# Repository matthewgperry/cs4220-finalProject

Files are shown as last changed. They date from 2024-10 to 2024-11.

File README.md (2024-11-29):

# Real-Time Embedded Systems (CS 4220/6235) Final Project - Fall 2024

## Overview

This repository contains the hardware schematics (PCB design files) in `occupancySensorBoard`, the initial Arduino scripts in `arduino`, and the ESP32 firmware in `firmware`.

The firmware defines an occupancy sensor with the DFRobot C4001 MM-Wave sensor with the Matter standard.

## Setup

Note: The ESP-IDF has an unresolved bug, requiring a manual workaround. The bug I experienced is described [here](https://esp32.com/viewtopic.php?t=42744).

1. Choose an install method for the ESP-IDF. I used the Linux install method. Follow the instructions [here](https://docs.espressif.com/projects/esp-idf/en/v5.3.1/esp32/get-started/index.html).

2. Install [ESP-Matter](https://docs.espressif.com/projects/esp-matter/en/latest/esp32/developing.html).

3. Clone this repository.

4. Source the ESP-IDF and ESP-Matter environment variables.

5. Navigate to the `firmware` directory.

6. Run `idf.py set-target esp32c6` to set the target board to the ESP32-C6.

7. Run `idf.py menuconfig` to configure the firmware (WiFi setup, flash size, etc).

8. Run `idf.py build` to build the firmware.

## PCB Production

The PCB design files are in the `occupancySensorBoard` directory. The PCB was designed in KiCad.

The PCB was produced by JLCPCB. The Gerber, BOM, and CPL files are in the `occupancySensorBoard/jlcpcb` directory.

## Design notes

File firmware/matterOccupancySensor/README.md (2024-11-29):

# Matter Occupany Sensor Firmware

## Description

This firmware, built with ESP-IDF v5.2.1, initalizes control of a DFRobot C4001 MM-Wave sensor and sends data to a variety of smart home hubs with the Matter framework.

## Setup

#### Clean Build

ESP-IDF seems to have issues fully removing the build directory, so do it manually.

#### Setting Target

In the demo case, an ESP32-C6 is used.
So `idf.py set-target esp32c6` should be ran.

#### Configuration

`idf.py menuconfig`

#### Building and Flash

`idf.py build flash monitor`

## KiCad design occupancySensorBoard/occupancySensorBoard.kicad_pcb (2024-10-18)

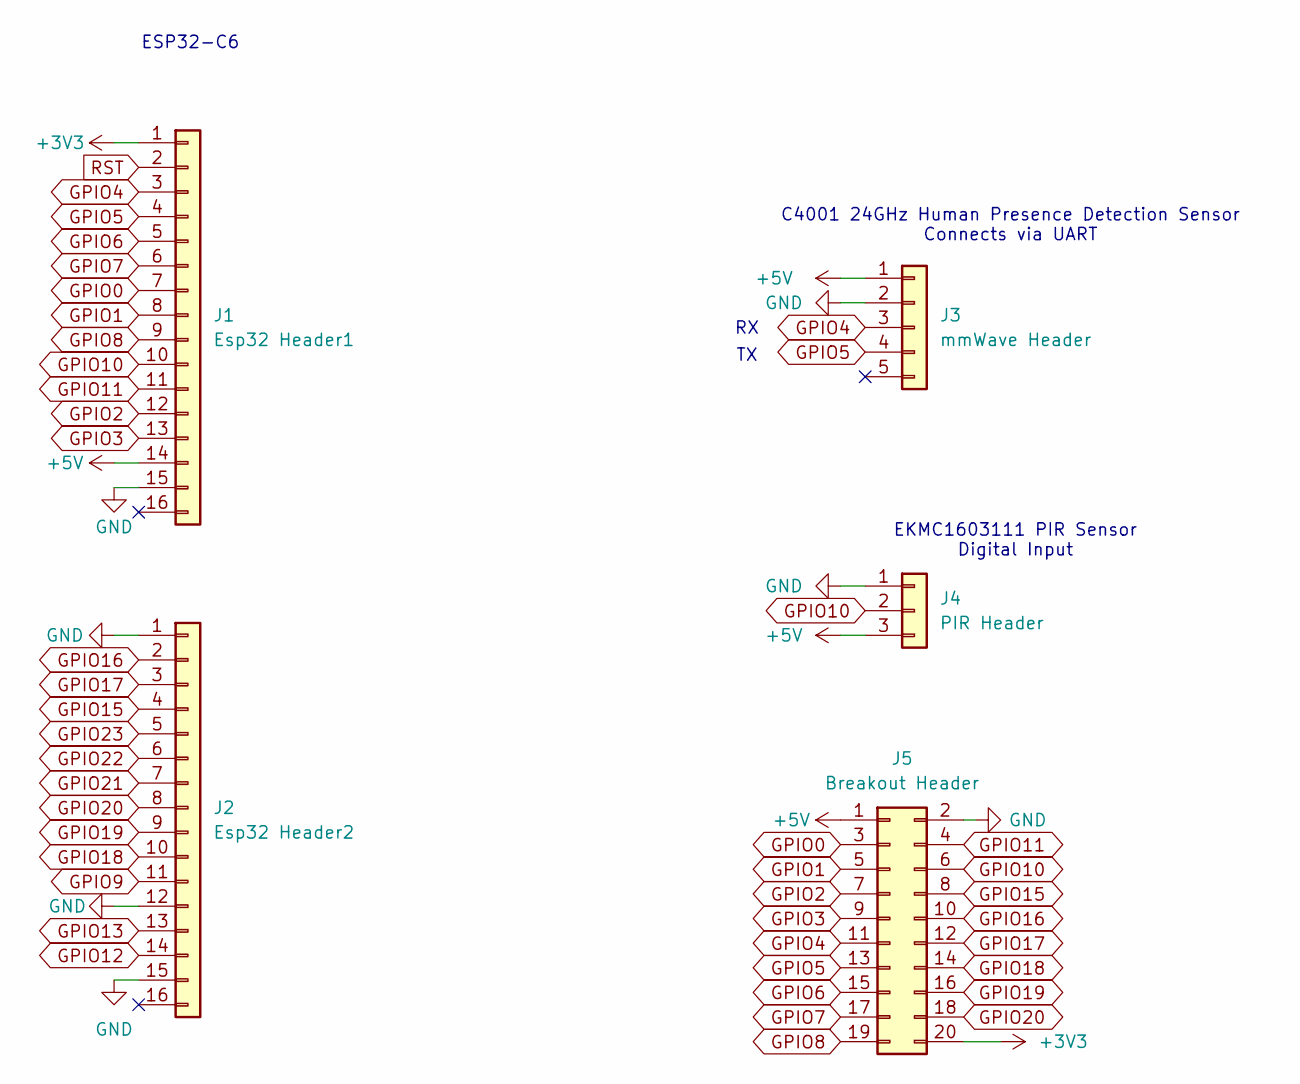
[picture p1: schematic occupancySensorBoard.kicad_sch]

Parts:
J1: Esp32 Header1; PinHeader_1x16_P2.54mm_Vertical
J2: Esp32 Header2; PinHeader_1x16_P2.54mm_Vertical
J3: mmWave Header; PinHeader_1x05_P2.54mm_Vertical
J4: PIR Header; 917-47-103-41005000
J5: Breakout Header; PinHeader_2x10_P2.54mm_Vertical

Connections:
+3V3: J1.1, J5.20
+5V: J1.14, J3.1, J4.3, J5.1
GND: J1.15, J2.1, J2.12, J2.15, J3.2, J4.1, J5.2
GPIO0: J1.7, J5.3
GPIO1: J1.8, J5.5
GPIO2: J1.12, J5.7
GPIO3: J1.13, J5.9
GPIO4: J1.3, J3.3, J5.11
GPIO5: J1.4, J3.4, J5.13
GPIO6: J1.5, J5.15
GPIO7: J1.6, J5.17
GPIO8: J1.9, J5.19
GPIO9: J2.11
GPIO10: J1.10, J4.2, J5.6
GPIO11: J1.11, J5.4
GPIO12: J2.14
GPIO13: J2.13
GPIO15: J2.4, J5.8
GPIO16: J2.2, J5.10
GPIO17: J2.3, J5.12
GPIO18: J2.10, J5.14
GPIO19: J2.9, J5.16
GPIO20: J2.8, J5.18
GPIO21: J2.7
GPIO22: J2.6
GPIO23: J2.5
RST: J1.2

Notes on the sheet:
C4001 24GHz Human Presence Detection Sensor Connects via UART
EKMC1603111 PIR Sensor Digital Input
ESP32-C6

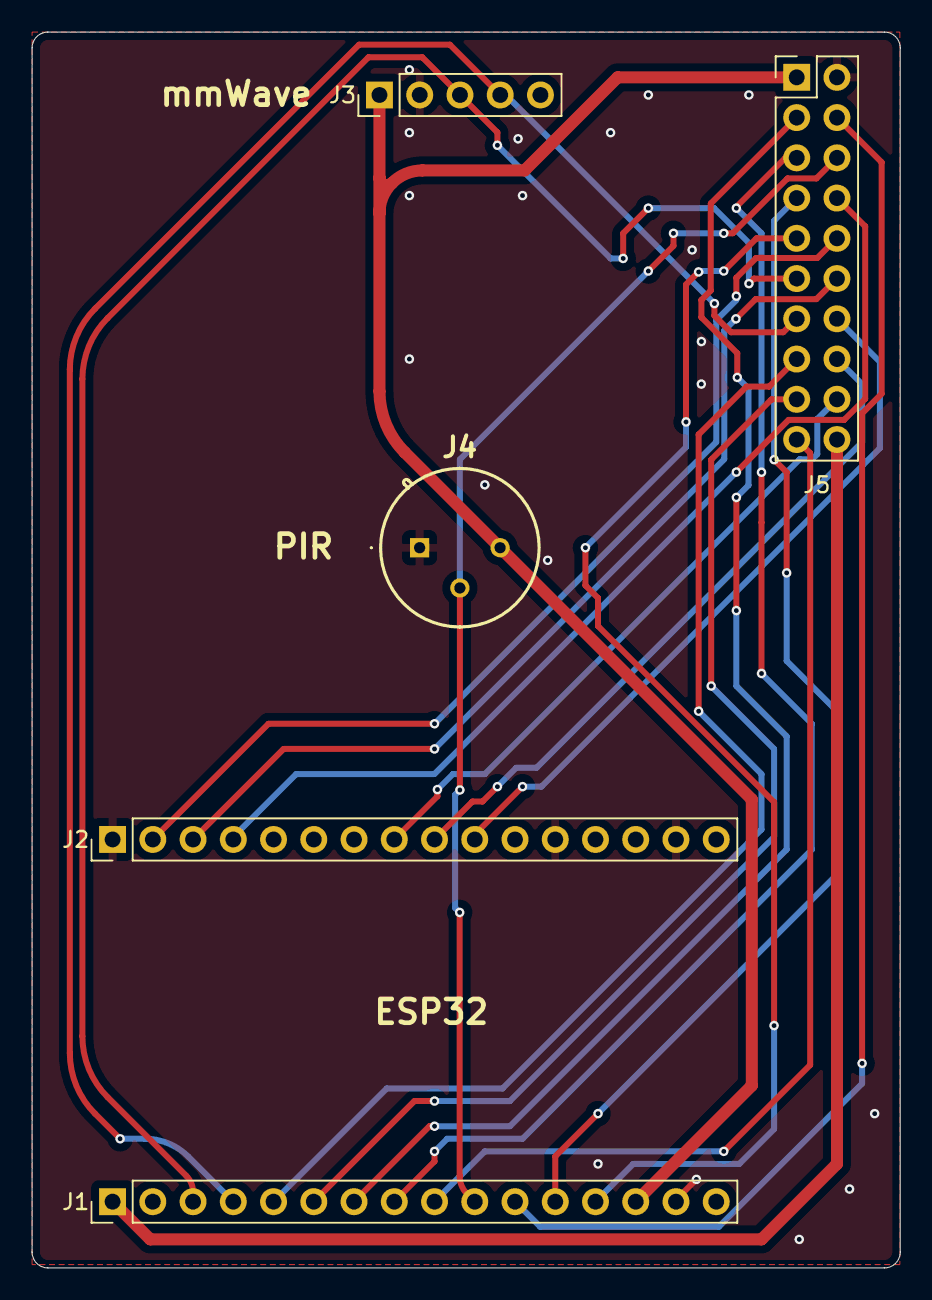
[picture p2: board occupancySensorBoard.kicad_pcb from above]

Board: 2 copper layers, 54.8 x 78.0 mm, 5 parts (0 on the bottom side), 20 nets.

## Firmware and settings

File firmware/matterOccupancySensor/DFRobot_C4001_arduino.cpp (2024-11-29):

/*!
 * @file DFRobot_C4001.cpp
 * @brief Define the basic structure of the DFRobot_C4001 class, the implementation of the basic methods
 * @copyright	Copyright (c) 2010 DFRobot Co.Ltd (http://www.dfrobot.com)
 * @license The MIT License (MIT)
 * @author [ZhixinLiu](zhixin.liu@dfrobot.com)
 * @version V1.0
 * @date 2024-02-02
 * @url https://github.com/DFRobot/DFRobot_C4001
 */
#include "DFRobot_C4001_arduino.h"

DFRobot_C4001::DFRobot_C4001(){}
DFRobot_C4001::~DFRobot_C4001(){}

sSensorStatus_t DFRobot_C4001::getStatus(void)
{
  sSensorStatus_t data;
  uint8_t temp[100] = {0};
  uint8_t len = 0;
  if(uartI2CFlag == I2C_FLAG){
    uint8_t temp = 0;
    readReg(REG_STATUS, &temp, (uint8_t)1);
    data.workStatus = (temp&0x01);
    data.workMode   = (temp&0x02) >> 1;
    data.initStatus = (temp&0x80) >> 7;
  }else{  
    sAllData_t allData;
    readReg(0, temp, 100);
    writeReg(0, (uint8_t *)START_SENSOR, strlen(START_SENSOR));
    while(len == 0){
      delay(1000);
      len = readReg(0, temp, 100);
      allData = anaysisData(temp ,len);
    }
    data.workStatus = allData.sta.workStatus;
    data.workMode   = allData.sta.workMode;
    data.initStatus = allData.sta.initStatus;
  }
  return data;
}

bool DFRobot_C4001::motionDetection(void)
{
  if(uartI2CFlag == I2C_FLAG){
    uint8_t temp = 0;
    readReg(REG_RESULT_STATUS, &temp, (uint8_t)1);
    if(temp&0x01){
      return true;
    }
    return false;
  }else{
    static bool old = false;
    uint8_t status = 0;
    uint8_t len = 0;
    uint8_t temp[100] = {0};
    sAllData_t data;
    len = readReg(0, temp, 100);
    data = anaysisData(temp ,len);
    if(data.exist){
      old = (bool)status;
      return (bool)data.exist;
    }else{
      return (bool)old;
    }
  }
}

void DFRobot_C4001::setSensor(eSetMode_t mode)
{
  uint8_t temp = mode;
  if(uartI2CFlag == I2C_FLAG){
    if(mode == eStartSen){
      writeReg(REG_CTRL0, &temp, (uint8_t)1);
      delay(200);  // must timer
    }else if(mode == eStopSen){
      writeReg(REG_CTRL0, &temp, (uint8_t)1);
      delay(200);  // must timer
    }else if(mode == eResetSen){
      writeReg(REG_CTRL0, &temp, (uint8_t)1);
      delay(1500);  // must timer
    }else if(mode == eSaveParams){
      writeReg(REG_CTRL1, &temp, (uint8_t)1);
      delay(500);  // must timer
    }else if(mode == eRecoverSen){
      writeReg(REG_CTRL1, &temp, (uint8_t)1);
      delay(800);  // must timer
    }else if(mode == eChangeMode){
      writeReg(REG_CTRL1, &temp, (uint8_t)1);
      delay(1500);  // must timer
    }
  }else{
    if(mode == eStartSen){
      writeReg(0, (uint8_t *)START_SENSOR, strlen(START_SENSOR));
      delay(200);  // must timer
    }else if(mode == eStopSen){
      writeReg(0, (uint8_t *)STOP_SENSOR, strlen(STOP_SENSOR));
      delay(200);  // must timer
    }else if(mode == eResetSen){
      writeReg(0, (uint8_t *)RESET_SENSOR, strlen(RESET_SENSOR));
      delay(1500);  // must timer
    }else if(mode == eSaveParams){
      writeReg(0, (uint8_t *)STOP_SENSOR, strlen(STOP_SENSOR));
      delay(200);  // must timer
      writeReg(0, (uint8_t *)SAVE_CONFIG, strlen(SAVE_CONFIG));
      delay(800);  // must timer
      writeReg(0, (uint8_t *)START_SENSOR, strlen(START_SENSOR));
    }else if(mode == eRecoverSen){
      writeReg(0, (uint8_t *)STOP_SENSOR, strlen(STOP_SENSOR));
      delay(200);
      writeReg(0, (uint8_t *)RECOVER_SENSOR, strlen(RECOVER_SENSOR));
      delay(800);  // must timer
      writeReg(0, (uint8_t *)START_SENSOR, strlen(START_SENSOR));
      delay(500);
    }
  }
}

bool DFRobot_C4001::setSensorMode(eMode_t mode)
{
  if(uartI2CFlag == I2C_FLAG){
    sSensorStatus_t data;
    data = getStatus();
    if(data.workMode == mode){
      return true;
    }else{
      setSensor(eChangeMode);
      data = getStatus();
      if(data.workMode == mode){
        return true;
      }else{
        return false;
      }
    }
  }else{
    sensorStop();
    if(mode == eExitMode){
      writeReg(0, (uint8_t *)EXIST_MODE, strlen(EXIST_MODE));
      delay(50);  
    }else{
      writeReg(0, (uint8_t *)SPEED_MODE, strlen(SPEED_MODE));
      delay(50);
    }
    delay(50);
    writeReg(0, (uint8_t *)SAVE_CONFIG, strlen(SAVE_CONFIG));
    delay(500);
    writeReg(0, (uint8_t *)START_SENSOR, strlen(START_SENSOR));
    delay(100);
    return true;
  }
}

bool DFRobot_C4001::setTrigSensitivity(uint8_t sensitivity)
{
  uint8_t temp = sensitivity;
  if(sensitivity > 9){
    return false;
  }
  if(uartI2CFlag == I2C_FLAG){
    writeReg(REG_TRIG_SENSITIVITY, &temp, (uint8_t)1);
    setSensor(eSaveParams);
    return true;
  }else{
    String data = "setSensitivity 255 1";
    data[19] = sensitivity + 0x30;
    writeCMD(data, data, (uint8_t)1);
    return true;
  }
}

uint8_t DFRobot_C4001::getTrigSensitivity(void)
{
  if(uartI2CFlag == I2C_FLAG){
    uint8_t temp = 0;
    readReg(REG_TRIG_SENSITIVITY, &temp, (uint8_t)1);
    return temp;
  }else{
    sResponseData_t responseData;
    uint8_t temp[100] = {0};
    readReg(0, temp, 100);
    String data = "getSensitivity";
    responseData = wRCMD(data, (uint8_t)1);
    if(responseData.status){ 
      return responseData.response1;
    }
    return 0;
  }
}

bool DFRobot_C4001::setKeepSensitivity(uint8_t sensitivity)
{
  uint8_t temp = sensitivity;
  if(sensitivity > 9){
    return false;
  }
  if(uartI2CFlag == I2C_FLAG){
    writeReg(REG_KEEP_SENSITIVITY, &temp, (uint8_t)1);
    setSensor(eSaveParams);
    return true;
  }else{
    String data = "setSensitivity 1 255";
    data[15] = sensitivity + 0x30;
    writeCMD(data, data, (uint8_t)1);
    return true;
  }
}

uint8_t DFRobot_C4001::getKeepSensitivity(void)
{
  if(uartI2CFlag == I2C_FLAG){
    uint8_t temp = 0;
    readReg(REG_KEEP_SENSITIVITY, &temp, (uint8_t)1);
    return temp;
  }else{
    sResponseData_t responseData;
    uint8_t temp[100] = {0};
    readReg(0, temp, 100);
    String data = "getSensitivity";
    responseData = wRCMD(data, (uint8_t)1);
    if(responseData.status){
      return responseData.response2;
    }
    return 0;
  }
}

bool DFRobot_C4001::setDelay(uint8_t trig , uint16_t keep)
{
  if(trig > 200){
    return false;
  }
  if(keep < 4 || keep > 3000){
    return false;
  }
  if(uartI2CFlag == I2C_FLAG){
    uint8_t temp[3] = {0};
    temp[0] = trig;
    temp[1] = keep;
    temp[2] = keep>>8;
    writeReg(REG_TRIG_DELAY, temp, (uint8_t)3);
    setSensor(eSaveParams);
    return true;
  }else{
    String data = "setLatency ";
    data += String((float)trig*0.01, 1);
    data += " ";
    data += String((float)keep*0.5, 1);
    writeCMD(data, data, (uint8_t)1);
    return true;
  }
}
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

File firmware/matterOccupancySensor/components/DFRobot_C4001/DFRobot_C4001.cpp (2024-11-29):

#include "DFRobot_C4001.h"
#include "driver/uart.h"
#include "esp_log.h"
#include "esp_timer.h"
#include <string>
#include <cstring>
#include <stddef.h>

#define UART_NUM UART_NUM_0
#define BUF_SIZE 1024
static const char *TAG = "DFRobot_C4001";

DFRobot_C4001::DFRobot_C4001() : _addr(DEVICE_ADDR_0) {
    memset(&_buffer, 0, sizeof(sPrivateData_t));
}

// Add the missing destructor definition
DFRobot_C4001::~DFRobot_C4001() {
}


DFRobot_C4001_UART::DFRobot_C4001_UART(int tx_pin, int rx_pin, uint32_t baud_rate)
    : DFRobot_C4001(), tx_pin(tx_pin), rx_pin(rx_pin), baud_rate(baud_rate) {}

bool DFRobot_C4001_UART::begin() {
    const uart_config_t uart_config = {
        .baud_rate = baud_rate,
        .data_bits = UART_DATA_8_BITS,
        .parity = UART_PARITY_DISABLE,
        .stop_bits = UART_STOP_BITS_1,
        .flow_ctrl = UART_HW_FLOWCTRL_DISABLE
    };
    uart_param_config(UART_NUM, &uart_config);
    uart_set_pin(UART_NUM, tx_pin, rx_pin, UART_PIN_NO_CHANGE, UART_PIN_NO_CHANGE);
    uart_driver_install(UART_NUM, BUF_SIZE * 2, 0, 0, NULL, 0);
    return true;
}


void DFRobot_C4001_UART::writeReg(uint8_t reg, uint8_t *data, uint8_t len) {
    uart_write_bytes(UART_NUM, (const char *)data, len);
}

int16_t DFRobot_C4001_UART::readReg(uint8_t reg, uint8_t *data, uint8_t len) {
    uint16_t i = 0;
    uint32_t start_time = esp_timer_get_time() / 1000;
    while ((esp_timer_get_time() / 1000) - start_time < TIME_OUT) {
        int length = 0;
        uart_get_buffered_data_len(UART_NUM, (size_t *)&length);
        if (length > 0) {
            int read_len = uart_read_bytes(UART_NUM, data + i, len - i, 20 / portTICK_RATE_MS);
            if (read_len > 0) {
                i += read_len;
                if (i >= len) return len;
            }
        }
    }
    return i;
}

void DFRobot_C4001::setSensor(eSetMode_t mode) {
    if (mode == eStartSen) {
        writeReg(0, (uint8_t *)START_SENSOR, strlen(START_SENSOR));
        vTaskDelay(pdMS_TO_TICKS(200));
    } else if (mode == eStopSen) {
        writeReg(0, (uint8_t *)STOP_SENSOR, strlen(STOP_SENSOR));
        vTaskDelay(pdMS_TO_TICKS(200));
    } else if (mode == eResetSen) {
        writeReg(0, (uint8_t *)RESET_SENSOR, strlen(RESET_SENSOR));
        vTaskDelay(pdMS_TO_TICKS(1500));
    } else if (mode == eSaveParams) {
        writeReg(0, (uint8_t *)STOP_SENSOR, strlen(STOP_SENSOR));
        vTaskDelay(pdMS_TO_TICKS(200));
        writeReg(0, (uint8_t *)SAVE_CONFIG, strlen(SAVE_CONFIG));
        vTaskDelay(pdMS_TO_TICKS(800));
        writeReg(0, (uint8_t *)START_SENSOR, strlen(START_SENSOR));
    } else if (mode == eRecoverSen) {
        writeReg(0, (uint8_t *)STOP_SENSOR, strlen(STOP_SENSOR));
        vTaskDelay(pdMS_TO_TICKS(200));
        writeReg(0, (uint8_t *)RECOVER_SENSOR, strlen(RECOVER_SENSOR));
        vTaskDelay(pdMS_TO_TICKS(800));
        writeReg(0, (uint8_t *)START_SENSOR, strlen(START_SENSOR));
        vTaskDelay(pdMS_TO_TICKS(500));
    }
}

bool DFRobot_C4001::motionDetection(void) {
    static bool old = false;
    uint8_t status = 0;
    uint8_t len = 0;
    uint8_t temp[100] = {0};
    sAllData_t data;
    len = readReg(0, temp, 100);
    data = anaysisData(temp, len);
    if (data.exist) {
        old = (bool)status;
        ESP_LOGI(TAG, "Occupancy: %d", (bool)status);
        return (bool)data.exist;
    } else {
        return (bool)old;
        ESP_LOGI(TAG, "Occupancy: %d", (bool)old);
    }
}

sAllData_t DFRobot_C4001::anaysisData(uint8_t* data, uint8_t len)
{
    sAllData_t allData;
    uint8_t location = 0;
    
    // Initialize the structure with zeros
    memset(&allData, 0, sizeof(sAllData_t));
    
    // Find the start of the data marked by '$'
    for(uint8_t i = 0; i < len; i++) {
        if(data[i] == '$') {
            location = i;
            break;
        }
    }
    
    // Return empty structure if no valid start found
    if(location == len) {
        return allData;
    }
    
    // Check for Human Presence Detection mode
    if(strncmp((const char *)(data + location), "$DFHPD", strlen("$DFHPD")) == 0) {
        allData.sta.workMode = eExitMode;
        allData.sta.workStatus = 1;
        allData.sta.initStatus = 1;
        
        if(data[location + 7] == '1') {
            allData.exist = 1;
        } else {
            allData.exist = 0;
        }
    }
    // Check for Speed Detection mode
    else if(strncmp((const char *)(data + location), "$DFDMD", strlen("$DFDMD")) == 0) {
        allData.sta.workMode = eSpeedMode;
        allData.sta.workStatus = 1;
        allData.sta.initStatus = 1;
        
        // Create a temporary buffer for string manipulation
        char temp_buffer[256];
        if (len - location >= sizeof(temp_buffer)) {
            return allData;
        }
        
        // Copy data to temporary buffer for safer manipulation
        memcpy(temp_buffer, data + location, len - location);
        temp_buffer[len - location] = '\0';
        
        char* saveptr;
        char* token = strtok_r(temp_buffer, ",", &saveptr);
        int index = 0;
        char* parts[8] = {NULL};
        
        // Parse the comma-separated values
        while (token != NULL && index < 8) {
            parts[index++] = token;
            token = strtok_r(NULL, ",", &saveptr);
        }
        
        // Check if we have enough parts
        if (index >= 6) {
            // Convert string values to appropriate types with error checking
            char* endptr;
            
            // Parse target number
            long number = strtol(parts[1], &endptr, 10);
            if (*endptr == '\0') {
                allData.target.number = (int)number;
            } else {
            }
            
            // Parse range (multiply by 100 as per original)
            float range = strtof(parts[3], &endptr);
            if (*endptr == '\0') {
                allData.target.range = range * 100;
            } else {
            }
            
            // Parse speed (multiply by 100 as per original)
            float speed = strtof(parts[4], &endptr);
            if (*endptr == '\0') {
                allData.target.speed = speed * 100;
            } else {
            }
            
            // Parse energy
            float energy = strtof(parts[5], &endptr);
            if (*endptr == '\0') {
                allData.target.energy = energy;
            } else {
            }
            
        } else {
        }
    } else {
    }
    
    return allData;
}
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
